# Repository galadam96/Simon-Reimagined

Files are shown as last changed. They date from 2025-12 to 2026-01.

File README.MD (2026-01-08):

# 🎮 Simon Reimagined  

Modern Embedded System Implementation of the Classic Simon Game  

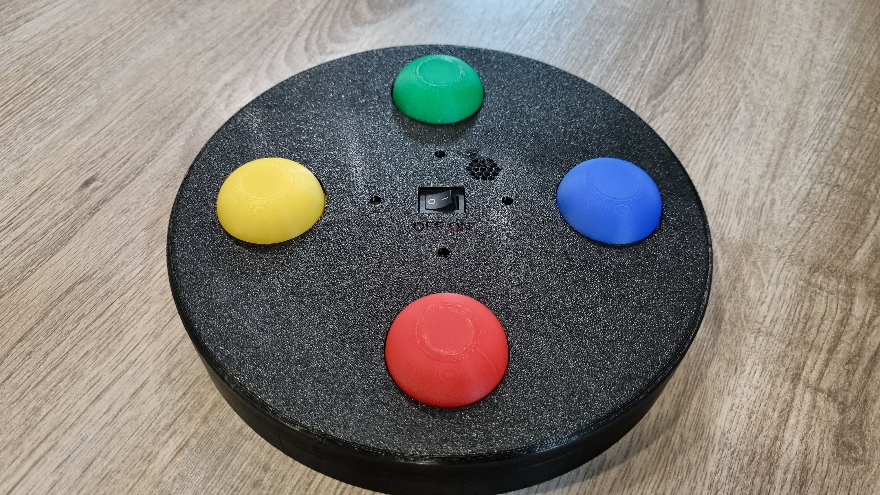
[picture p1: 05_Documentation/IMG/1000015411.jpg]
IMAGE ALT TEXT (http://www.youtube.com/watch?v=DPunw0gCDcM)


## 📌 Overview
Simon Reimagined is a fully redesigned, modern embedded version of the classic Simon memory game.  
The project includes:

- Custom circular PCB (V1.0)
- Arduino Nano–based firmware
- 3D‑printed mechanical housing
- Complete schematics and assembly documentation
- Tinkercad simulation environment
- Professional, print‑ready project documentation

## 🧠 Features
- Four colored buttons with matching LEDs  
- Unique tone for each color  
- Randomly generated sequences  
- Error feedback (audio + visual)  
- Power switch and buzzer  
- Fully custom PCB and enclosure  

## 🛠 Hardware Architecture

## Components
- Arduino Nano (ATmega328P)
- 4× momentary push buttons (Red, Blue, Green, Yellow)
- 4× LEDs with current‑limiting resistors
- Buzzer (4 kHz)
- ON/OFF toggle switch
- Custom circular PCB (designed in EasyEDA)
- 3D‑printed top/bottom housing + latch + buttons

## 💾 Firmware

## Language & Platform
- Arduino IDE (C/C++)
- State‑machine based game logic
- Debounced button input
- Tone generation per color

See the arudino code [here](https://github.com/galadam96/Simon-Reimagined/blob/main/00_Software/SimonGame_V1_4/SimonGame_V1_4.ino)

## 🧪 Simulation
Tinkercad simulation includes:

- Button logic
- LED feedback
- Buzzer tones
- Sequence playback

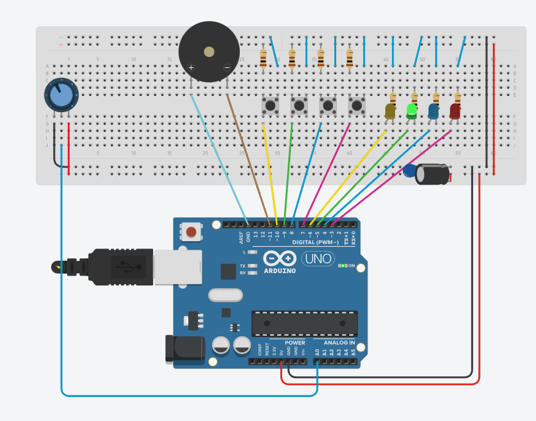
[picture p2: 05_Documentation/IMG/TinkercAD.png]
tinkercad


## 📄 Documentation
A full, print‑ready A4 documentation package is included
Cick [here](https://github.com/galadam96/Simon-Reimagined/blob/main/05_Documentation/Simon_Reimagined_Documentation.pdf) to read it! 

## 📜 License
This project is released under the MIT License.
Feel free to use, modify, and build upon it.

## 👤 Author
Adam Gal  
Embedded Systems Engineer

⭐ If you like this project
Consider giving the repository a star to support my work.

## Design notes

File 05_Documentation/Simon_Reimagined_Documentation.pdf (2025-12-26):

### SIMON REIMAGINED

### Embedded System Project Documentation

### Created by: Adam Gal Version: 1.0

### Date: 2025.12.26

### Project Summary

### A modern reinterpretation of the classic Simon memory game, featuring:

### - Custom PCB

### - Arduino Nano firmware

### - 3D-printed mechanical design

### - Full simulation & testing

### - Complete assembly documentation

### Portfolio Use

### Personal Embedded Engineering Portfolio Project

### © 2025 – Simon Reimagined Project – All rights reserved

### 1. Project Overview

Simon Reimagined is a redesigned memory game based on the classic Simon toy, built around an Arduino Nano microcontroller. The goal is to create a fully functional embedded system that challenges users to memorize and repeat increasingly complex sequences of lights and sounds. The project includes a custom PCB, 3D-printed

housing, and documented firmware.

### 2. Hardware Architecture

### 2.1 Key Components

### - Arduino Nano – microcontroller

### - 4 colored push buttons – user input (red, blue, green, yellow)

### - 4 LEDs – visual feedback

### - Buzzer – audio feedback

### - Toggle switch (ON/OFF) – power control

### - Custom circular PCB – central layout for all components

### 2.2 PCB Design

### Designed by Adam Gal using EasyEDA. Version: V1.0. Included documents:

### - SCH_v1.pdf – schematic diagram

### - Bottom_Plastic.pdf, Top_Plastic.pdf, Latch_Plastic.pdf, Button.pdf – mechanical drawings

### - Assembly.pdf – assembly guide

### 3. Firmware

### 3.1 Features

### - Game start: triggered by a dedicated start button

### - Sequence generation: random color and tone sequence

### - User input: player repeats the sequence

### - Error handling: incorrect input triggers buzzer and LED feedback, then resets

### 4. Mechanical Design

### 4.1 3D Structure

### The housing consists of fourt main parts:

### - Bottom shell – mounting points and power access

### - Top shell – cutouts for buttons and LEDs

### - Latch element – stabilizes button placement

### - Buttons - Custom-designed colored plastic buttons aligned with top shell

cutouts.

### 5. Simulation and Testing

### Simulated in Tinkercad:

### - LED and buzzer behavior

### - Button input and game logic

### - Voltage monitoring and debugging

### 6. Assembly

### Based on Assembly.pdf:

### - Mount Arduino Nano

### - Connect buttons and LEDs

### - Attach buzzer and toggle switch

### - Assemble housing (screws and alignment)

### 7. Attachments

### - Firmware code (Arduino IDE compatible)

### - SCH and PCB designs (EasyEDA)

### - Mechanical drawings (PDF format)

### - 3D renders and photos of the final device

### - Simulation environment (Tinkercad)

//DATE: 2025.10.08
//Author: Gal Adam
// ========================================
// SIMON GAME - Arduino Nano
// ========================================
// A memory game where players repeat an increasingly long sequence of colors. // - 4 colored buttons with LEDs
// - Buzzer for audio feedback
// - Green button (index 2) is used to start the game

// ----- PIN CONFIGURATION -----
const int BUTTON_PINS[4] = {10, 9, 8,7}; // Button inputs (with internal pullup)
const int LED_PINS[4] = {3, 4, 5, 6}; | // LED outputs for each color
const int BUZZER_PIN = 11; | // Buzzer output

// ----- AUDIO TONES -----
const int TONES[4] = {310, 209, 415, 252}; // Unique tone for each color

// ----- GAME VARIABLES -----
const int MAX_SEQUENCE = 100; | // Maximum sequence length
int sequence[MAX_SEQUENCE]; | // Stores the color sequence
int sequenceLength = 0; | // Current sequence length
int userInputIndex = 0; | // Tracks user's position in sequence

// ----- GAME STATES -----
enum GameState {
WELCOME, | // Show startup animation
WAIT_FOR_START, // Wait for player to press start button PLAY_SEQUENCE, // Display the sequence to memorize
USER_INPUT, | // Wait for player to repeat the sequence
GAME_OVER | // Show game over animation
};
GameState gameState = WELCOME;

// ----- DEBOUNCE TIMING -----
unsigned long lastButtonPress = 0; | // Last button press timestamp
const unsigned long debounceDelay = 200; | // Minimum time between button
presses (ms)

// ========================================
// SETUP
// ========================================
void setup() {
// Configure button pins with internal pullup resistors for (int i = 0; i < 4; i++) {
pinMode(BUTTON_PINS[i], INPUT_PULLUP); pinMode(LED_PINS[i], OUTPUT);
}

pinMode(BUZZER_PIN, OUTPUT);

}

// ======================================== // MAIN LOOP
// ======================================== void loop() {
switch (gameState) {
case WELCOME:
welcomeSequence();
gameState = WAIT_FOR_START; break;

case WAIT_FOR_START:
if (waitForStartButton()) {
sequenceLength = 0;
digitalWrite(LED_PINS[2], LOW); // Turn off blinking LED delay(500); // Short pause after start button press gameState = PLAY_SEQUENCE;
}
break;

case PLAY_SEQUENCE:
addToSequence();
playSequence();
userInputIndex = 0;
lastButtonPress = millis(); // Reset debounce timer gameState = USER_INPUT;
break;

case USER_INPUT:
{
int input = readButton();
if (input != -1) {
playColor(input);

// Check if input matches the sequence if (input != sequence[userInputIndex]) { gameState = GAME_OVER;
} else {
userInputIndex++;
// Check if entire sequence was entered correctly if (userInputIndex >= sequenceLength) { delay(500);
gameState = PLAY_SEQUENCE;
}
}
}
}
break;

case GAME_OVER:
gameOver();
gameState = WAIT_FOR_START; break;
}
}

// ======================================== // ADD NEW COLOR TO SEQUENCE
// ========================================
// Adds a random color to the sequence.
// Ensures first color is never green (to avoid confusion with start button). void addToSequence() {
if (sequenceLength < MAX_SEQUENCE) {
int newColor;
do {
newColor = random(0, 4);
} while (sequenceLength == 0 && newColor == 2); // First color cannot be green

sequence[sequenceLength++] = newColor;
}
}

// ======================================== // PLAY ENTIRE SEQUENCE

// ========================================
// Plays back the current sequence for the player to memorize. void playSequence() {
for (int i = 0; i < sequenceLength; i++) { playColor(sequence[i]);
delay(300); // Pause between colors
}
}

// ========================================
// PLAY SINGLE COLOR
// ========================================
// Lights up LED and plays tone for a single color. void playColor(int index) {
int duration = 150;

digitalWrite(LED_PINS[index], HIGH); tone(BUZZER_PIN, TONES[index], duration); delay(duration);
digitalWrite(LED_PINS[index], LOW);
}

// ======================================== // READ BUTTON INPUT
// ========================================
// Non-blocking button read with debounce.
// Returns button index (0-3) or -1 if no button pressed. int readButton() {
// Debounce: ignore inputs that are too close together if (millis() - lastButtonPress < debounceDelay) { return -1;
}

// Check each button
for (int i = 0; i < 4; i++) {
if (digitalRead(BUTTON_PINS[i]) == LOW) { lastButtonPress = millis();

// Wait for button release
while (digitalRead(BUTTON_PINS[i]) == LOW) { delay(10);
}

return i;
}
}
return -1;
}

// ======================================== // GAME OVER ANIMATION
// ======================================== // Flashes all LEDs and plays error sound. void gameOver() {
delay(300); // Wait for button release

// Flash all LEDs 3 times with low buzzer tone for (int i = 0; i < 3; i++) { tone(BUZZER_PIN, 100, 200);
for (int j = 0; j < 4; j++) { digitalWrite(LED_PINS[j], HIGH); }
delay(200);
noTone(BUZZER_PIN);

for (int j = 0; j < 4; j++) { digitalWrite(LED_PINS[j], LOW); }
delay(200);
}

delay(1000); // Pause before allowing restart }

// ========================================
// WELCOME ANIMATION
// ========================================
// Plays startup sequence: cascade effect followed by synchronized flashes. void welcomeSequence() {
int duration = 150;

// Cascade: each color lights up in sequence (2 times)
for (int repeat = 0; repeat < 2; repeat++) {
for (int i = 0; i < 4; i++) { digitalWrite(LED_PINS[i], HIGH); tone(BUZZER_PIN, TONES[i], duration); delay(duration);
digitalWrite(LED_PINS[i], LOW); noTone(BUZZER_PIN);
delay(100);
}
}

// Synchronized flash: all colors at once (4 times) for (int repeat = 0; repeat < 4; repeat++) {
for (int i = 0; i < 4; i++) { digitalWrite(LED_PINS[i], HIGH);
}
tone(BUZZER_PIN, 400, duration); delay(duration);
noTone(BUZZER_PIN);
for (int i = 0; i < 4; i++) { digitalWrite(LED_PINS[i], LOW); }
delay(150);
}
}

// ========================================
// WAIT FOR START BUTTON
// ========================================
// Non-blocking function that blinks green LED while waiting for start button. // Returns true when start button (green, index 2) is pressed.
bool waitForStartButton() {
static unsigned long previousMillis = 0;
const long interval = 300; // Blink interval (ms)
static bool ledState = false;

unsigned long currentMillis = millis();

// Toggle LED at regular intervals
if (currentMillis - previousMillis >= interval) { previousMillis = currentMillis;
ledState = !ledState;
digitalWrite(LED_PINS[2], ledState ? HIGH : LOW); }

// Check if start button is pressed
if (digitalRead(BUTTON_PINS[2]) == LOW) {

while (digitalRead(BUTTON_PINS[2]) == LOW) { delay(10); // Wait for button release
}
return true;
}

return false;
}

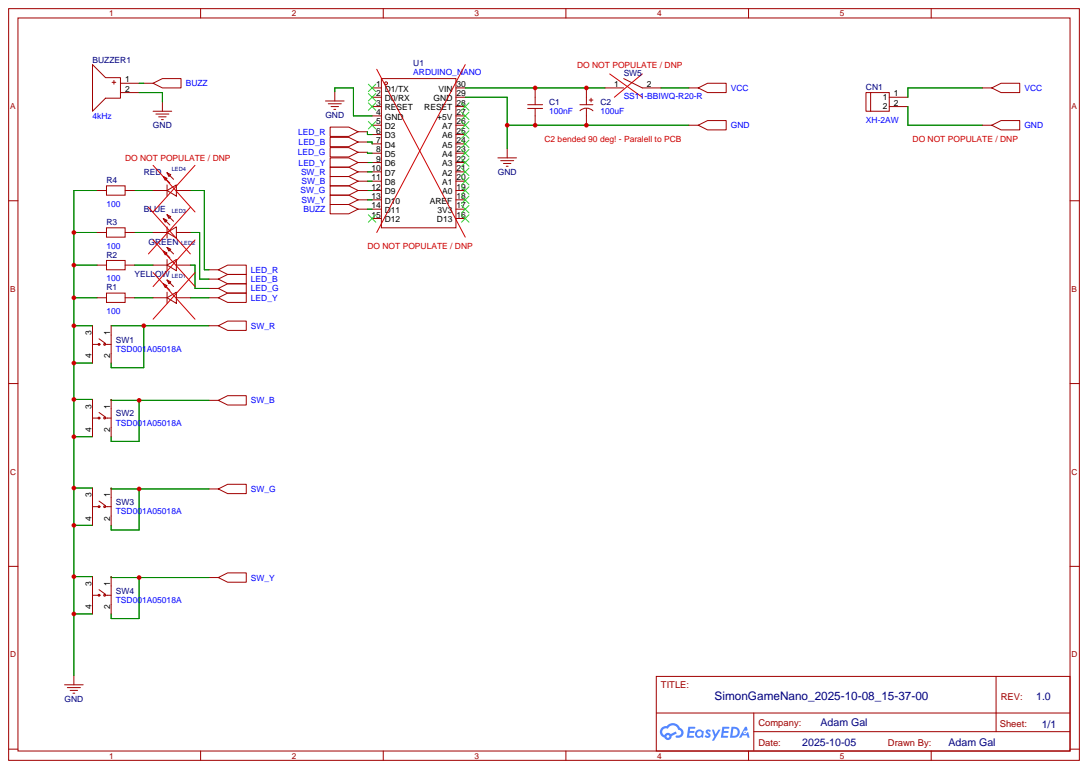
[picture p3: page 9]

DO NOT POPULATE / DNP

C2 bended 90 deg! - Paralell to PCB

LED4 RED

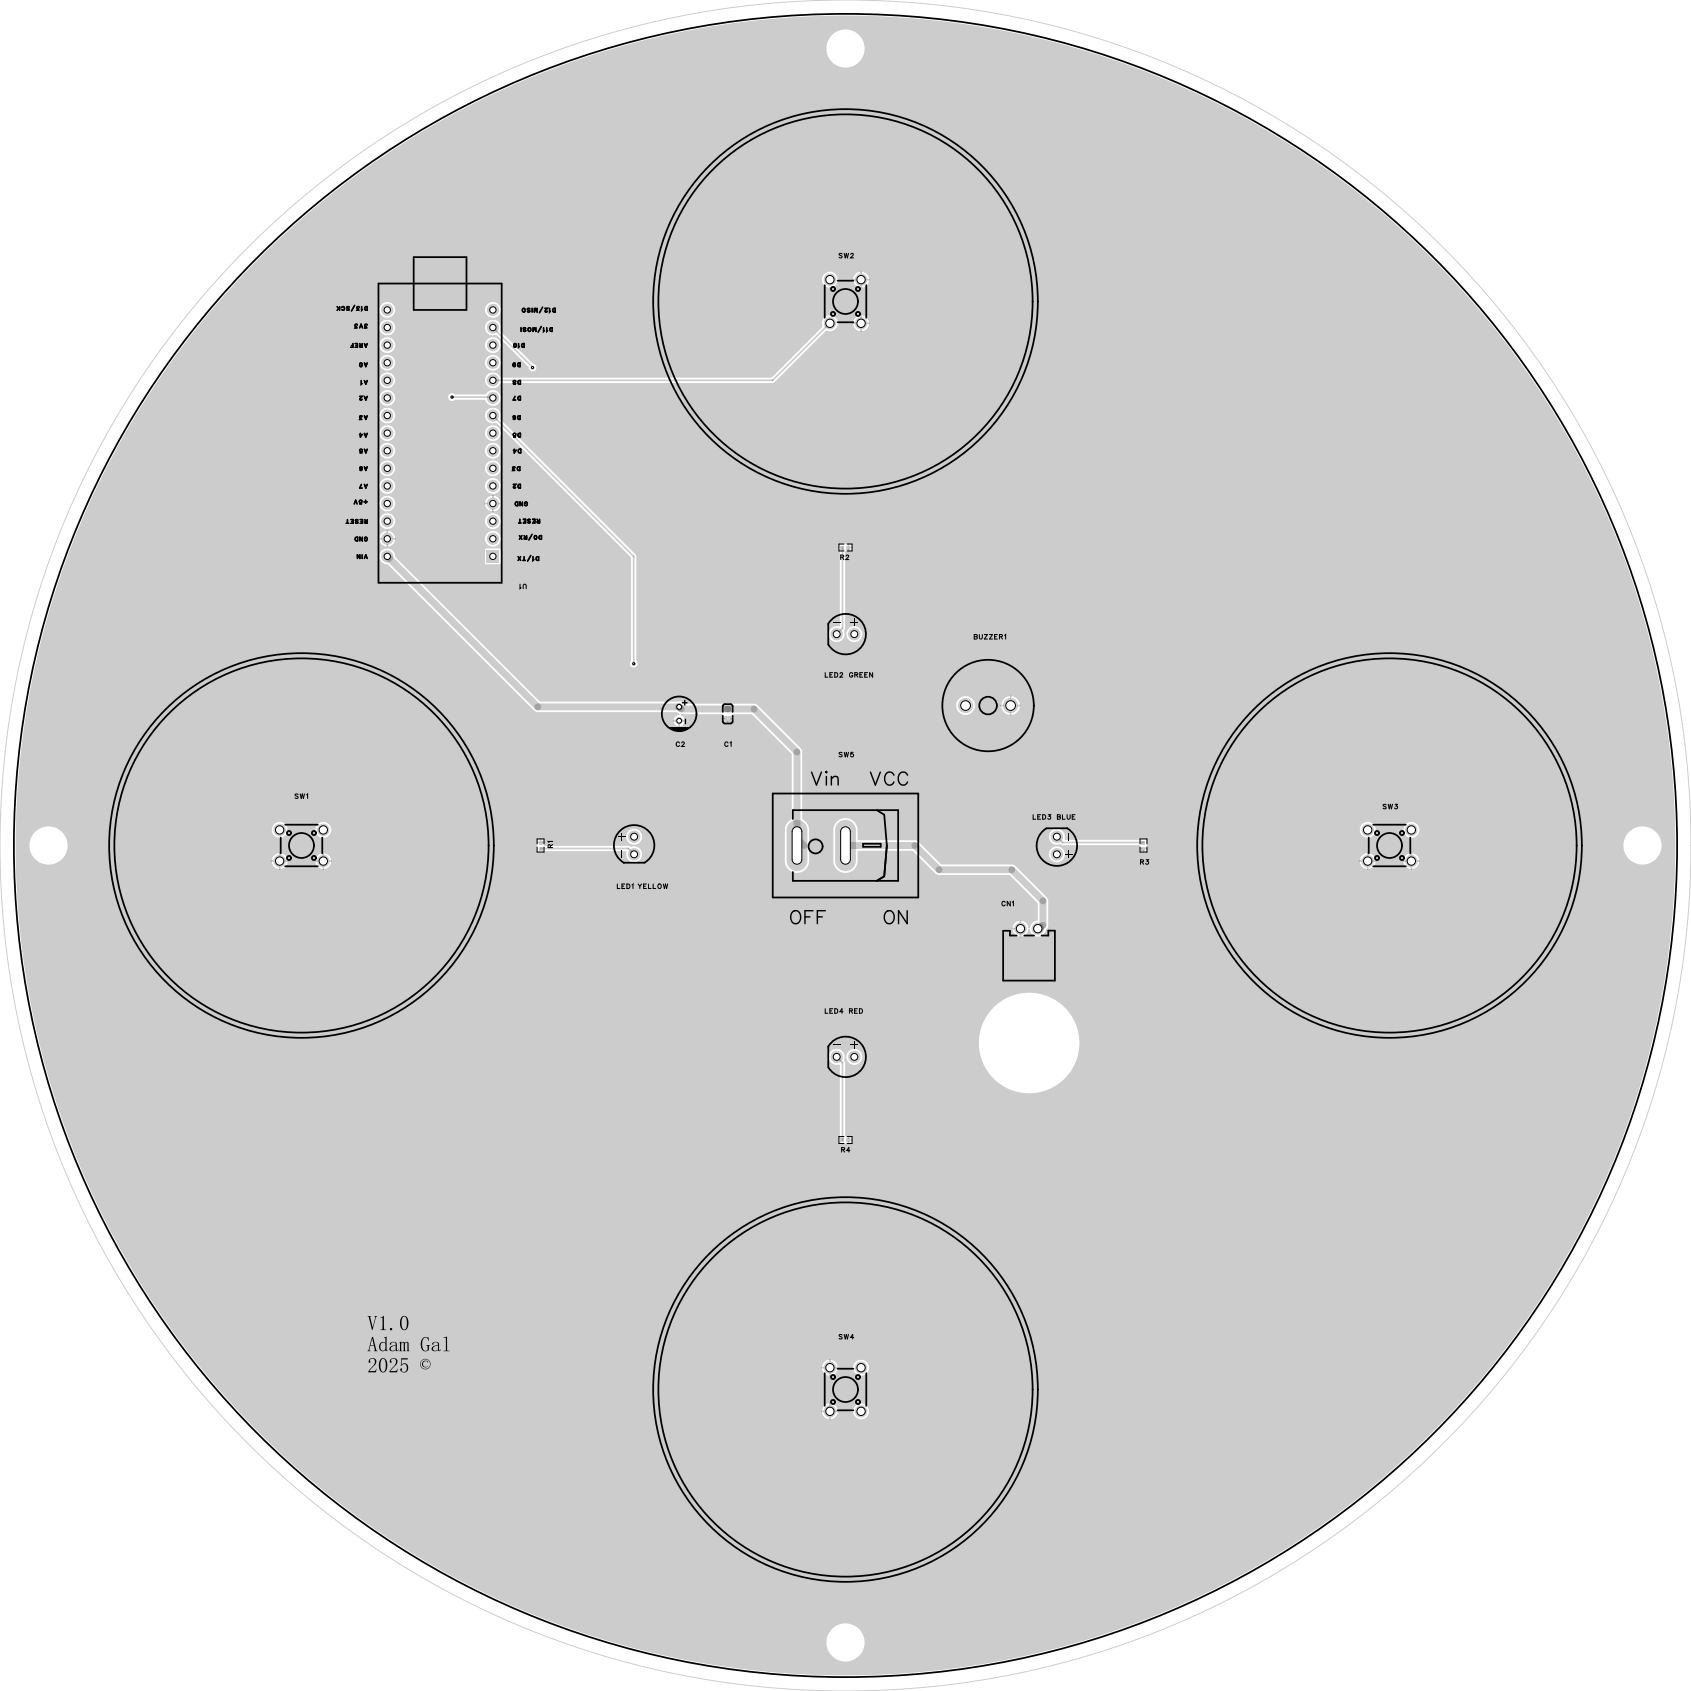
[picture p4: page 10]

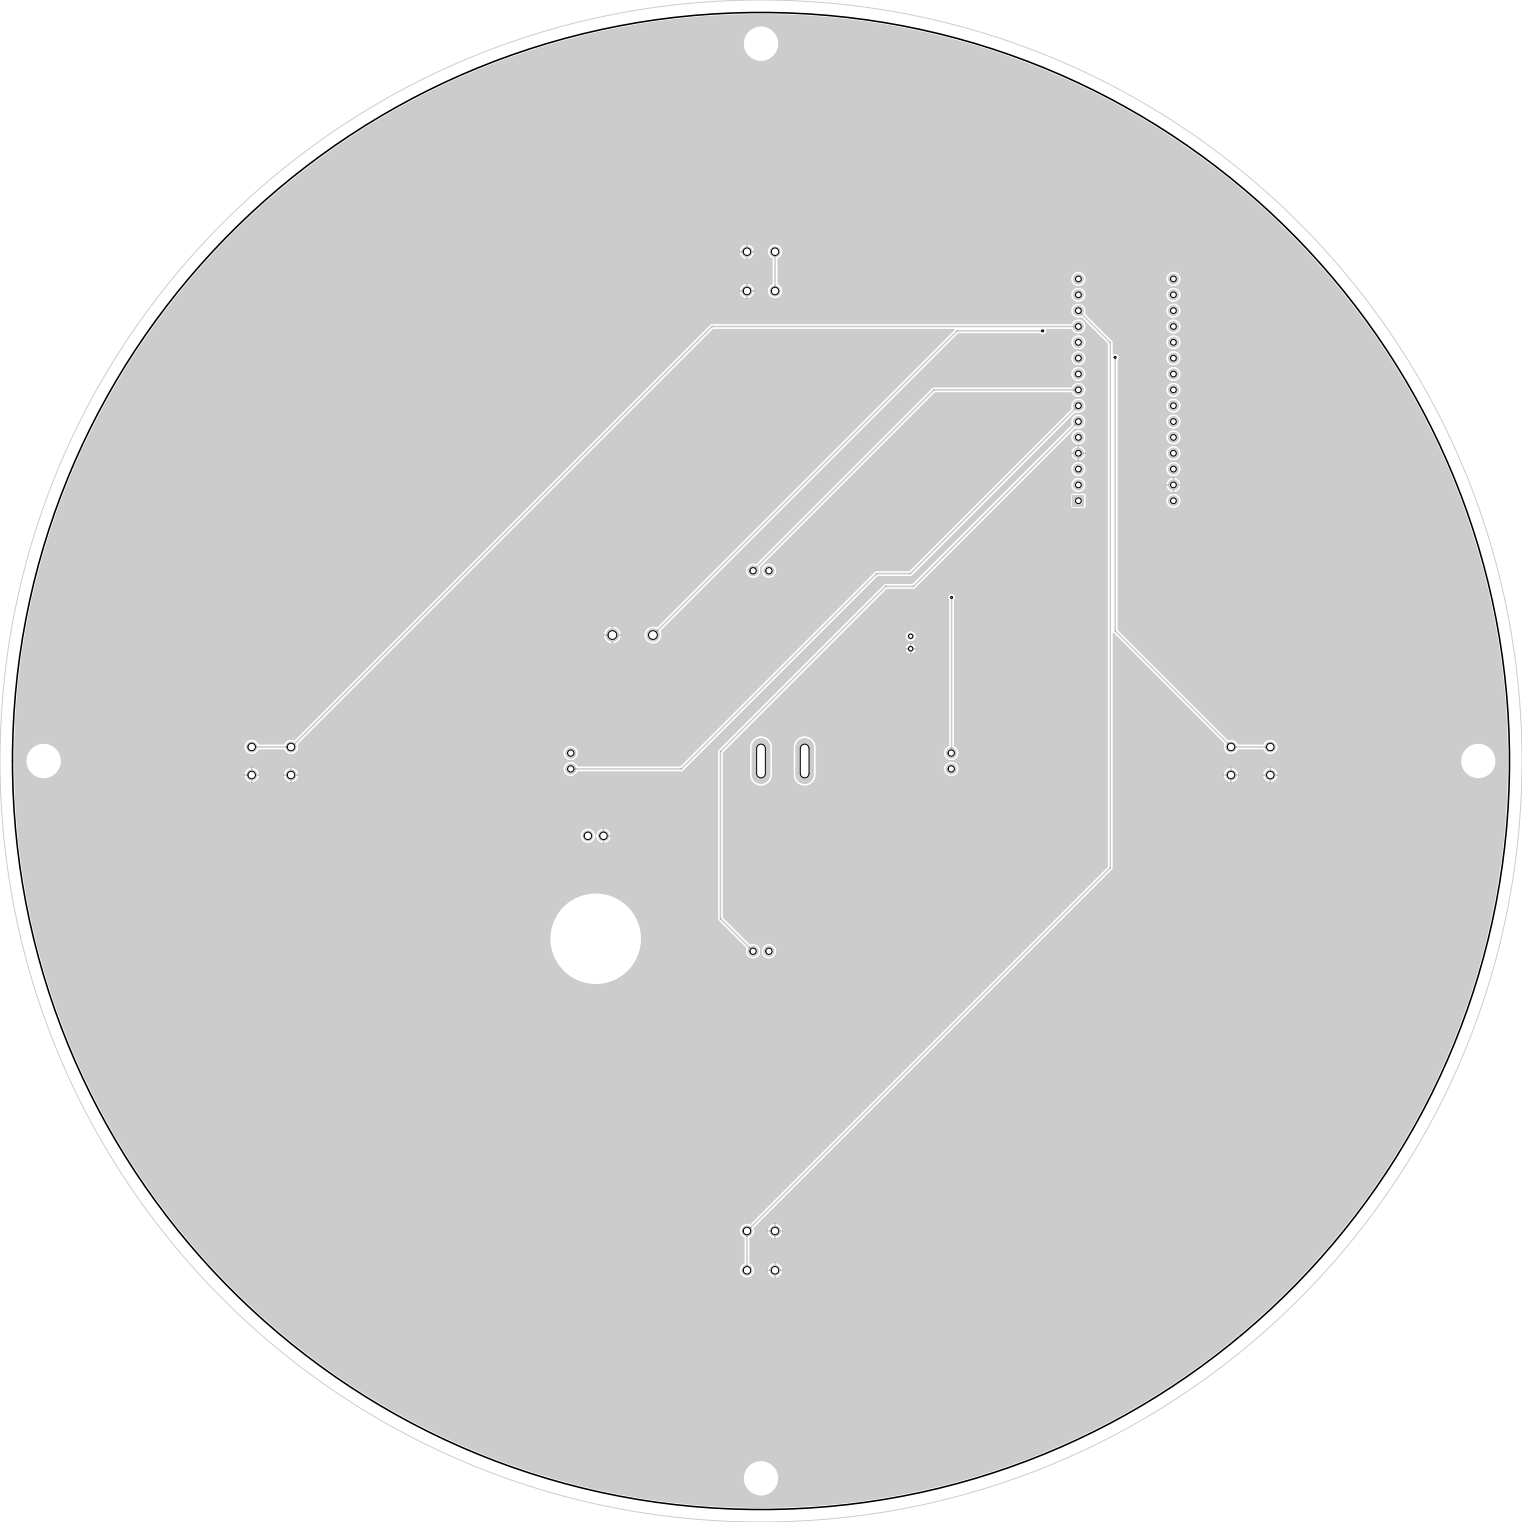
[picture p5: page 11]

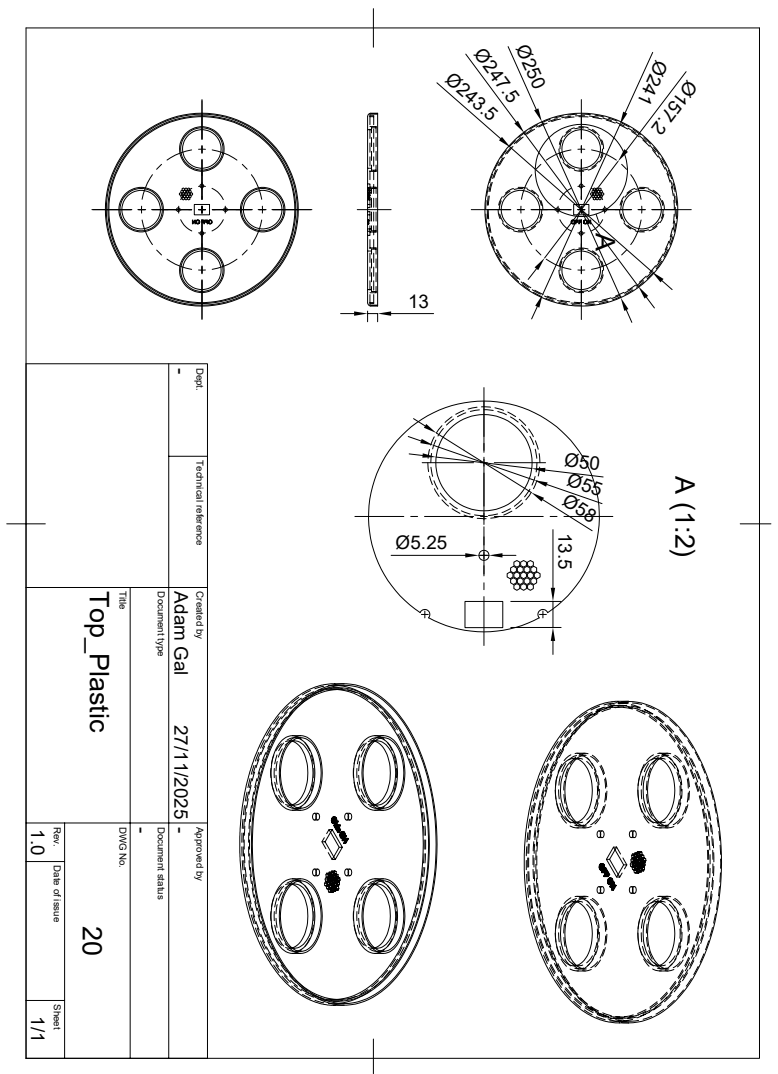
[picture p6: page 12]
- 27/11/2025 1/1 20 Top_Plastic; - Adam Gal -

Dept. Technical reference Created by Approved by Title DWG No. Document type Document status 1.0 Rev. Date of issue Sheet

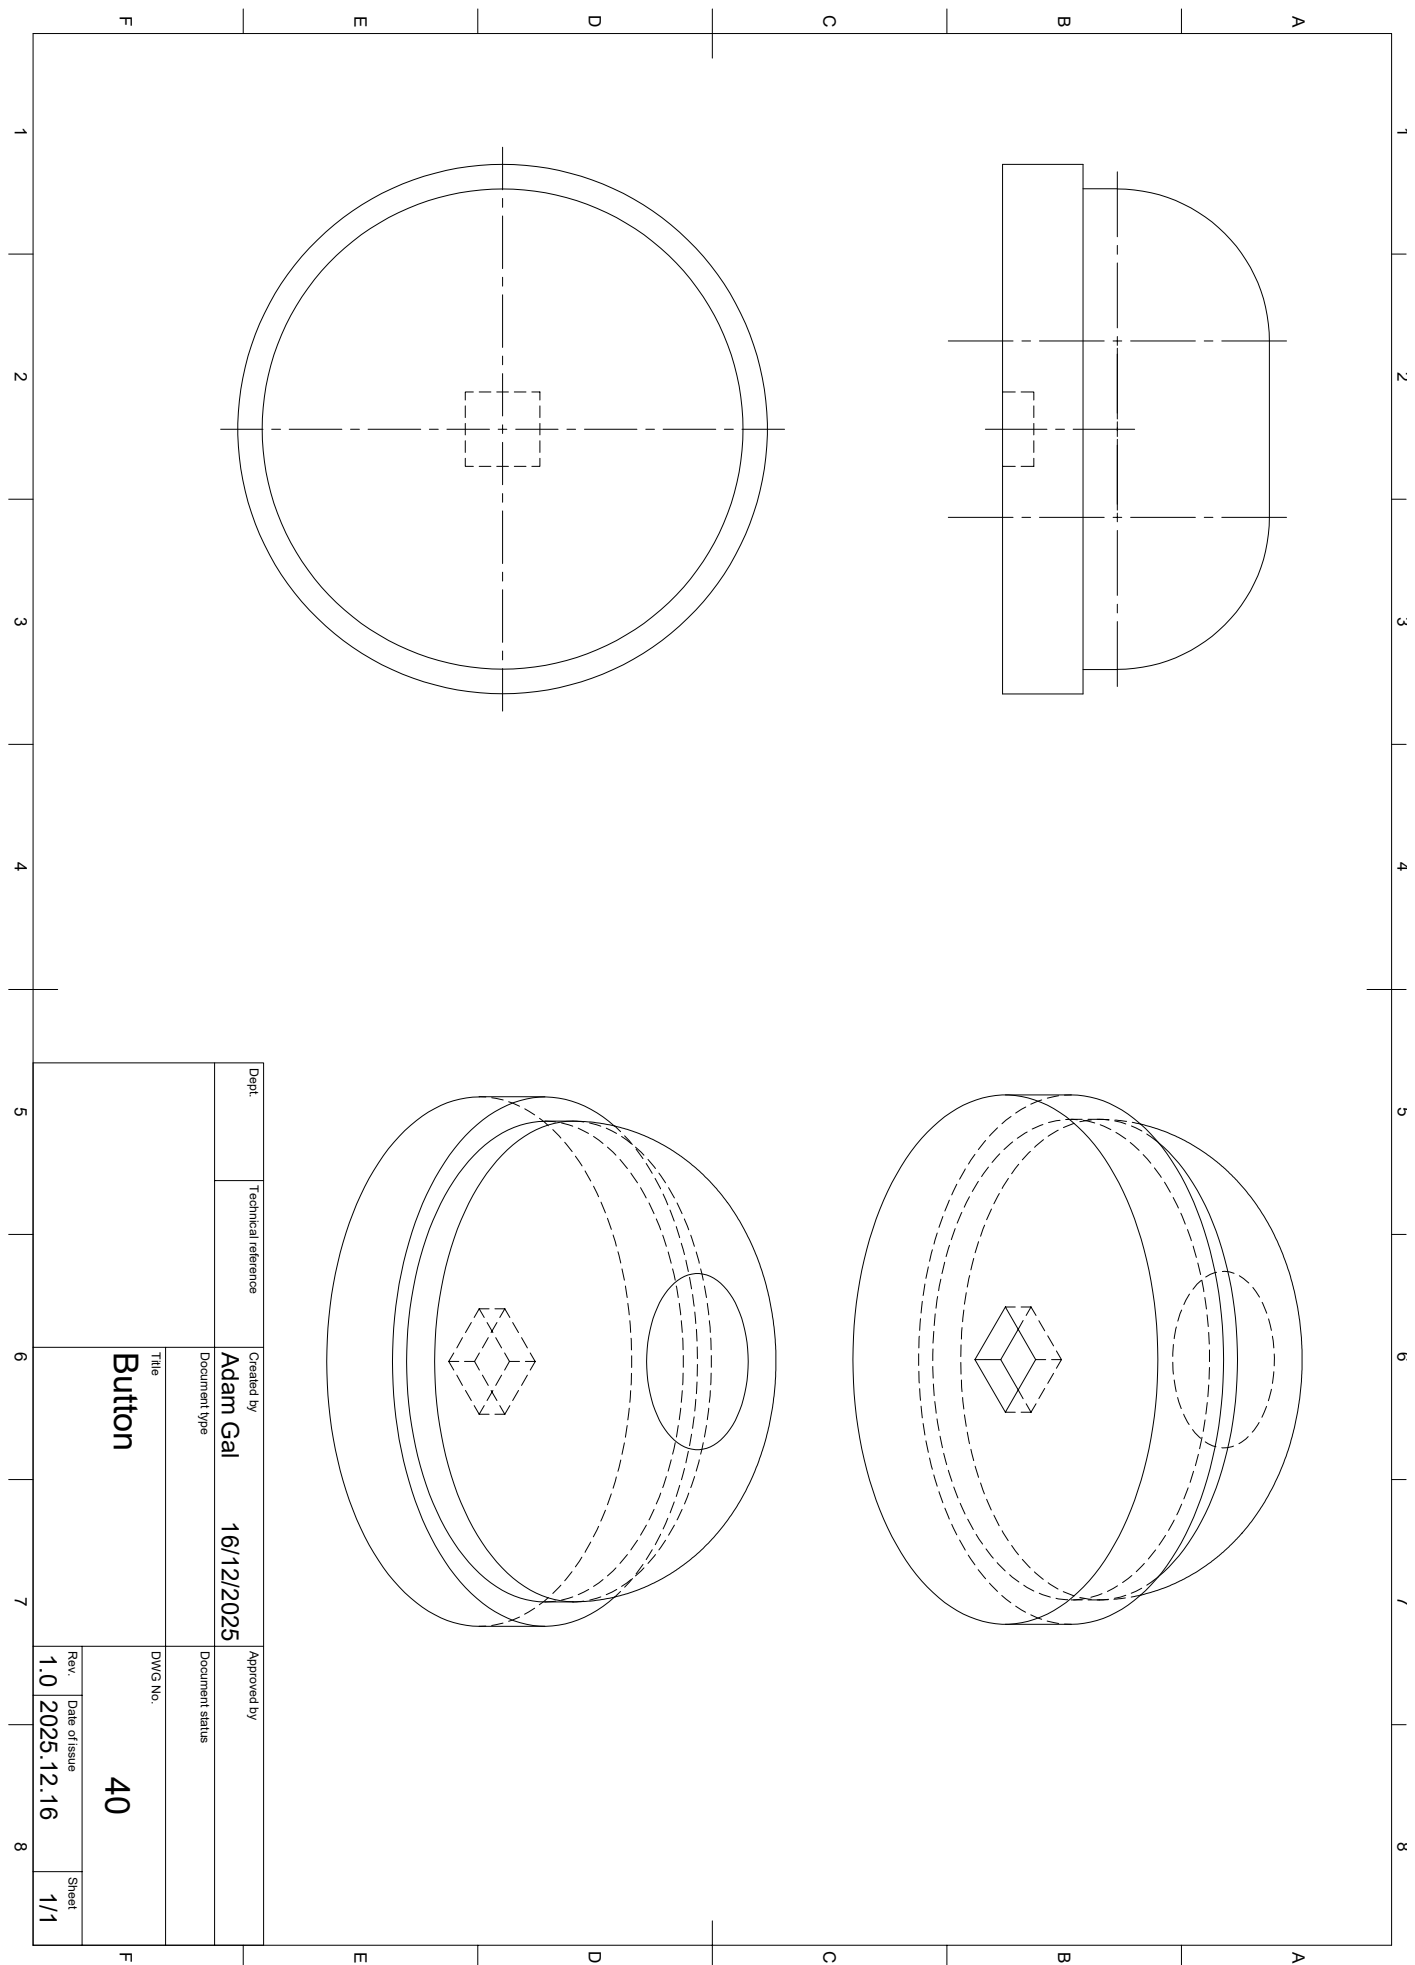
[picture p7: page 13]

1 A 2 3 4 5 6 7 8 1 2 3 4 5 6 7 8 FEDCB FEDCBA Dept. Technical reference Created by Approved by Title DWG No. Document type Document status Rev. Date of issue Sheet 2025.12.16 1.0 16/12/2025 1/1 40 Button Adam Gal

20

# 30 Ø14

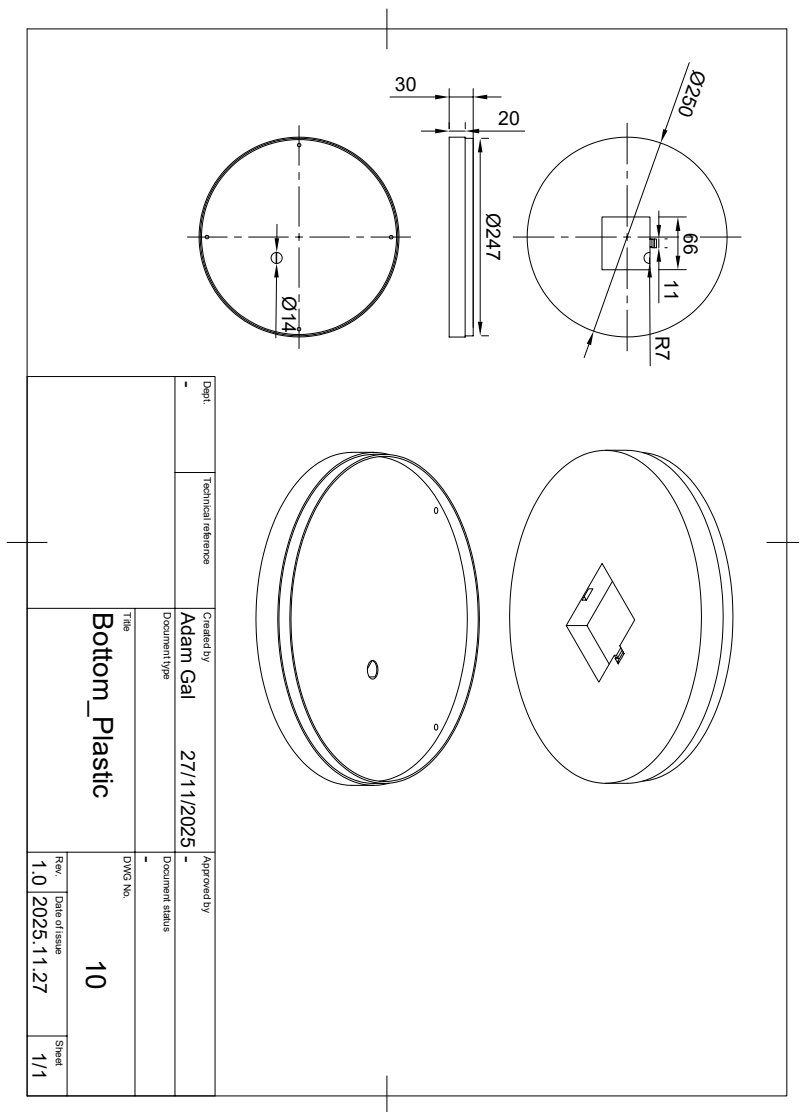
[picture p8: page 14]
- Adam Gal

Dept. Technical reference Created by Approved by Title DWG No. Document type Document status Rev. Date of issue Sheet 2025.11.27 1.0 - 27/11/2025 1/1 10 Bottom_Plastic

65
10

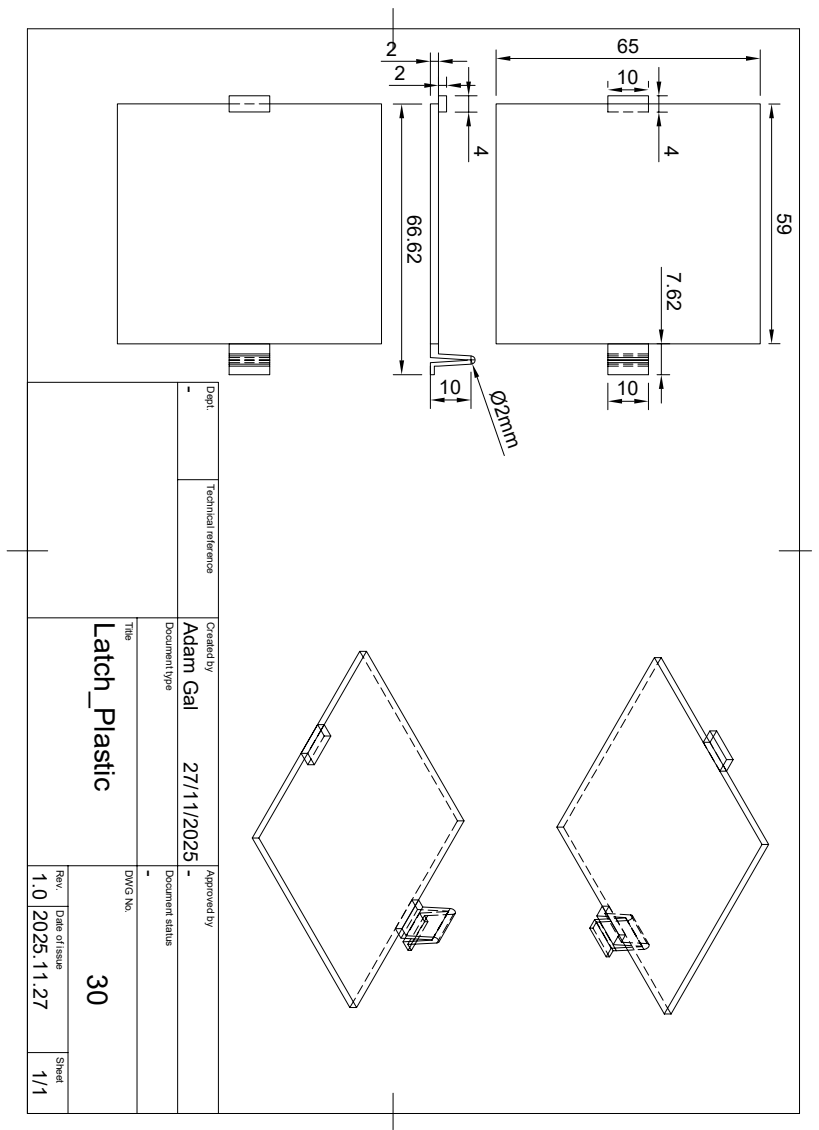
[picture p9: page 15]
- Adam Gal - 59

Dept. Technical reference Created by Approved by Title DWG No. Document type Document status Rev. Date of issue Sheet 2025.11.27 1.0 - 27/11/2025 1/1 30 Latch_Plastic

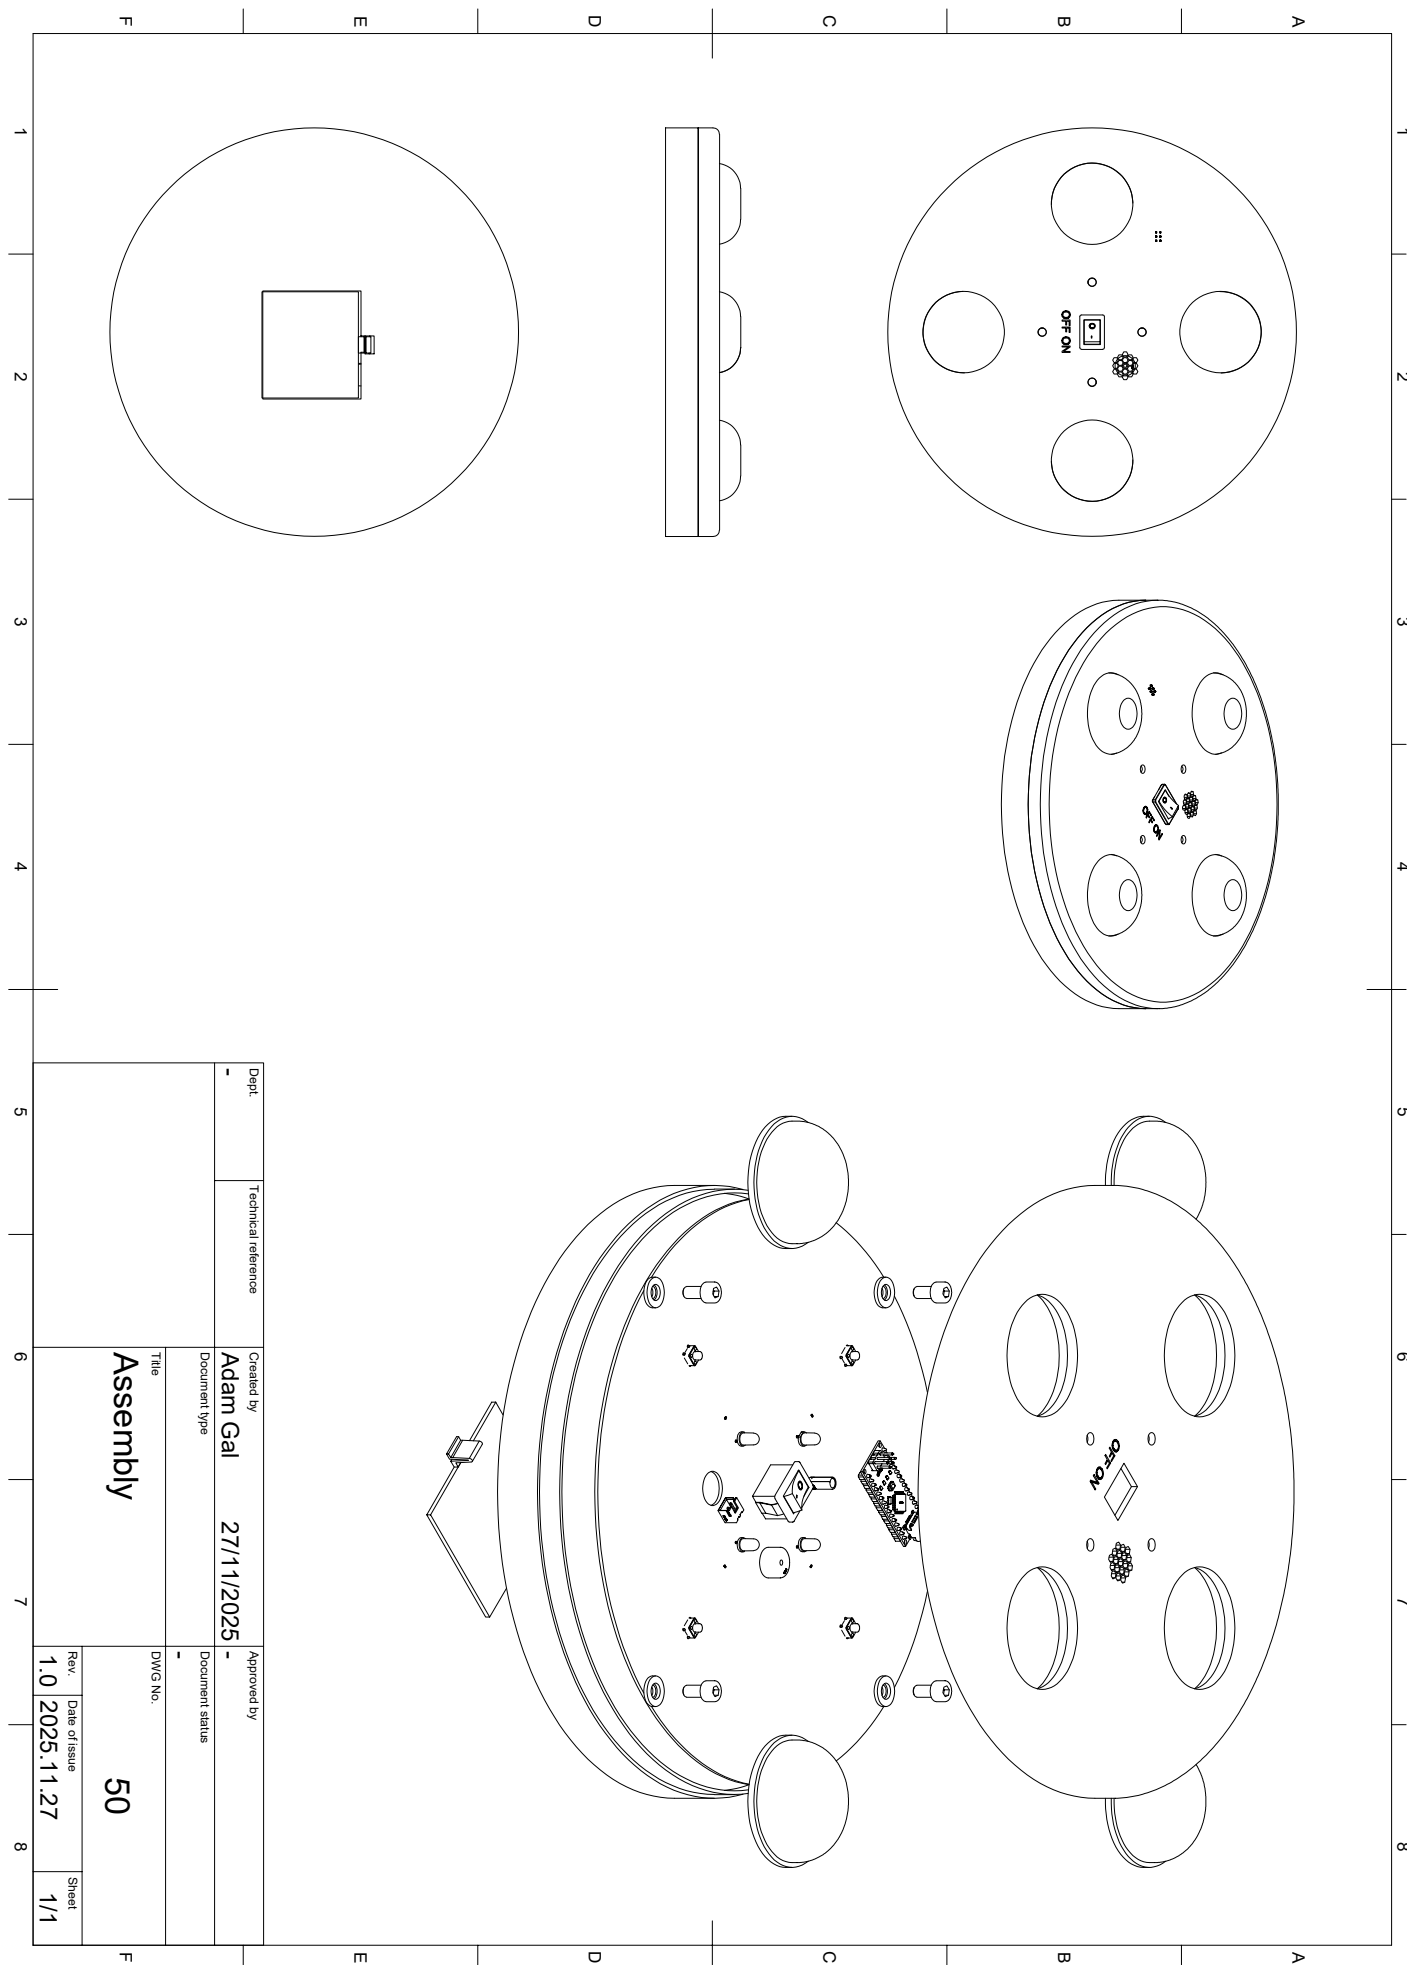
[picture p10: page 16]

1 A 2 3 4 5 6 7 8 1 2 3 4 5 6 7 8 FEDCB FEDCBA Dept. Technical reference Created by Approved by Title DWG No. Document type Document status Rev. Date of issue Sheet 2025.11.27 1.0 - 27/11/2025 1/1 50 Assembly - Adam Gal -

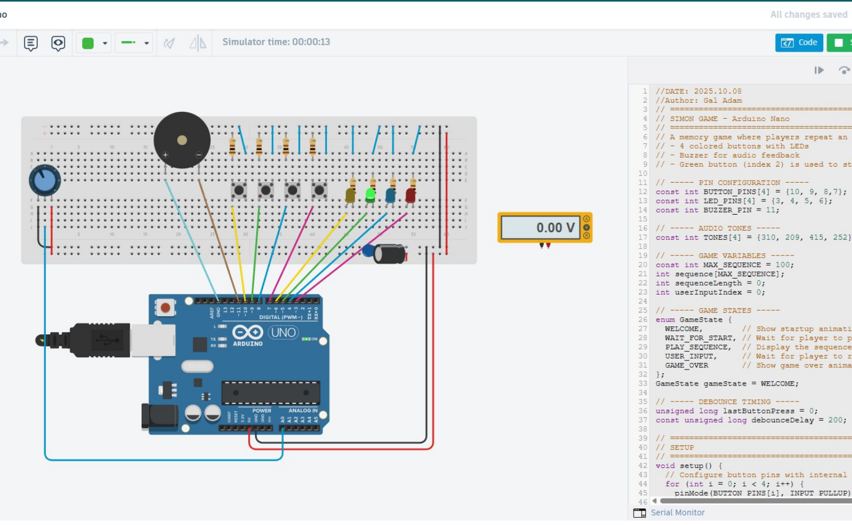
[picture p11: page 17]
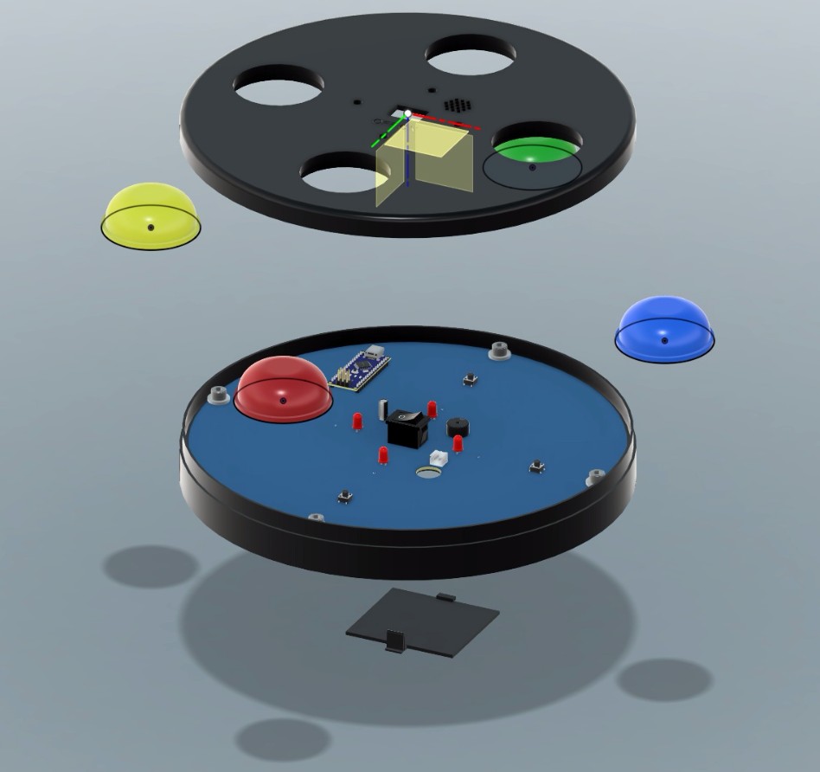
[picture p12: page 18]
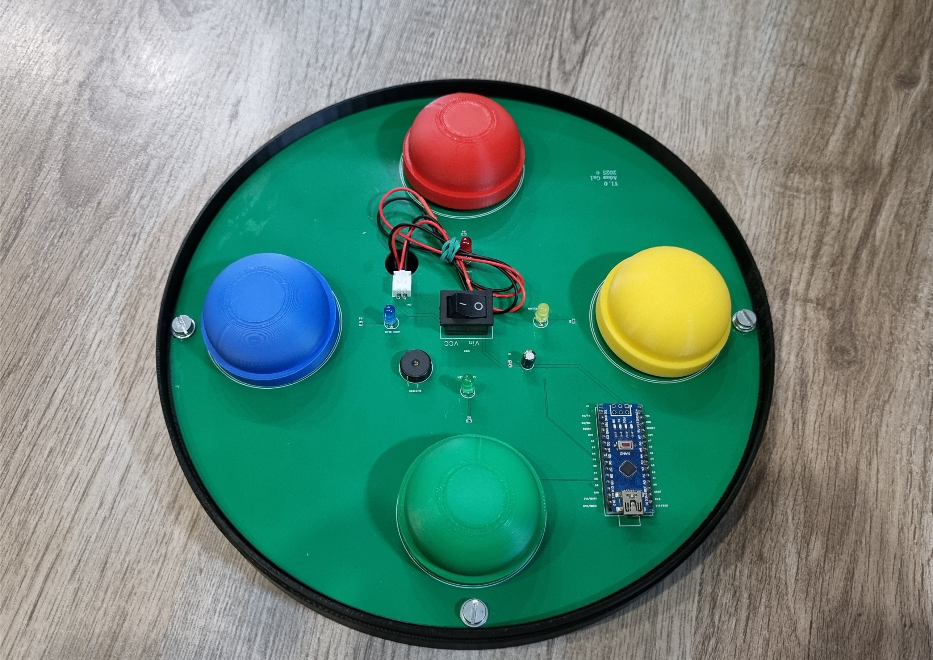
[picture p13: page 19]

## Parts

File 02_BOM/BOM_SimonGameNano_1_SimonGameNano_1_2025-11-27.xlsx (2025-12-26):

No. | Quantity | Comment | Designator | Footprint | Value | Manufacturer Part | Manufacturer | Supplier Part | Supplier | JLCPCB Stock | JLCPCB Price | Unique ID | Symbol | Name | Device
1 | 1 | 4kHz | BUZZER1 | BUZ-TH_BD12.5-P6.50-D1.4 | 4kHz | 1255-P6.5MM | XHXDZ(兴华鑫) | C49246963 | LCSC | 910 | 0.0076 | gge1 | 1255-P6.5MM | 4kHz | 1255-P6.5MM
2 | 1 | 100nF | C1 | C0603 | 100nF | TCC0603X7R104K250CT | CCTC(三环) | C7501158 | LCSC | 30739 | 0.0003 | gge12 | TCC0603X7R104K250CT | 100nF | TCC0603X7R104K250CT
3 | 1 | 100uF | C2 | CAP-TH_BD5.0-P2.00-D0.5-FD-1 | 100uF | 16V100uF CD288 | HRK(鸿瑞凯电子) | C2960195 | LCSC | 41190 | 0.0021 | gge13 | 16V100UF CD288 | 100uF | 16V100uF CD288
4 | 1 | XH-2AW | CN1 | CONN-TH_2P-P2.50_XH-2AW |  | XH-2AW | BOOMELE(博穆精密) | C33132 | LCSC | 82562 | 0.0012 | gge15 | XH-2AW | XH-2AW | XH-2AW_C33132
5 | 4 | 333-2SURD/S530-A3 | LED1,LED2,LED3,LED4 | LED-TH_BD5.9-P2.54-RD_RED |  | 333-2SURD/S530-A3 | EVERLIGHT(亿光) | C87271 | LCSC | 56201 | 0.0045 | BLUE,GREEN,RED,YELLOW | 333-2SURD/S530-A3 | 333-2SURD/S530-A3 | 333-2SURD/S530-A3
6 | 4 | 100Ω | R1,R2,R3,R4 | R0402 | 100Ω | SCR0402J100R | VO(翔胜) | C3017466 | LCSC | 7186 | 0.0001 | gge3,gge4,gge5,gge6 | SCR0402J100R | 100Ω | SCR0402J100R
7 | 4 | TSD001A05018A | SW1,SW2,SW3,SW4 | SW-TH_4P-L6.0-W6.0-P4.50-LS6.3 |  | TSD001A05018A | BZCN(博众电气) | C2888545 | LCSC | 3219 | 0.0016 | gge7,gge8,gge9,gge10 | TSD001A05018A | TSD001A05018A | TSD001A05018A
8 | 1 | SS11-BBIWQ-R20-R | SW5 | SW-TH_SS11-BBIWQ-XX |  | SS11-BBIWQ-R20-R | Legion(六钧) | C309066 | LCSC | 2057 | 0.0424 | gge16 | SS11-BBIWQ-R20-R | SS11-BBIWQ-R20-R | SS11-BBIWQ-R20-R
9 | 1 | ARDUINO_NANO | U1 | ARDUINO_NANO |  | ARDUINO_NANO | null | C9900017879 | LCSC | 0 | 0.0053 | gge5e3b22db8fd4dd14 | ARDUINO_NANO | ARDUINO_NANO | ARDUINO_NANO

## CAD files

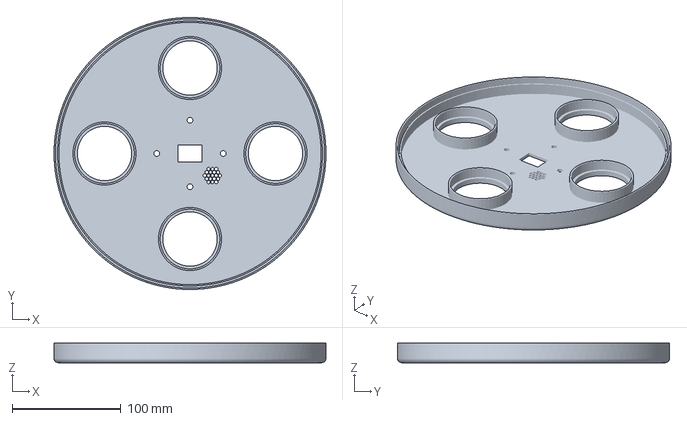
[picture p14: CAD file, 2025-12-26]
04_3D_STP/00_Print_Files/Top_v3_print.3mf
250.0 x 250.0 x 18.0 mm

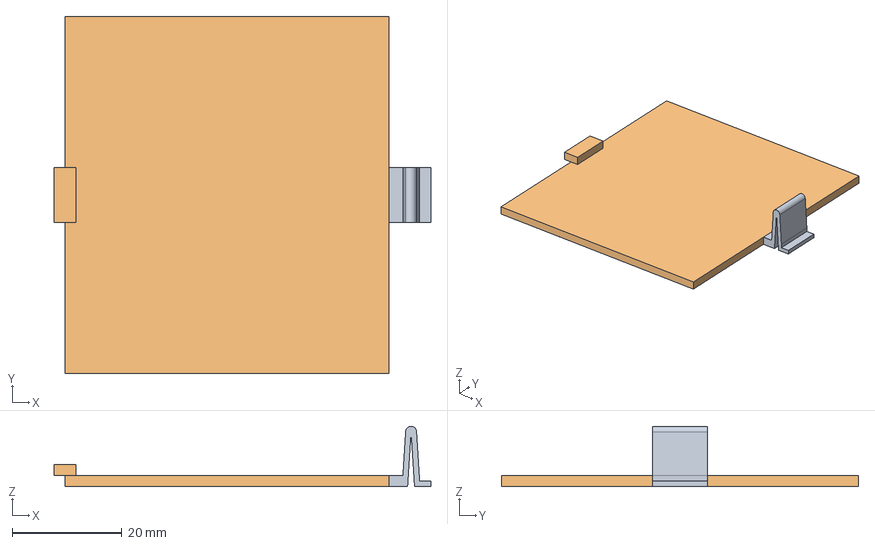
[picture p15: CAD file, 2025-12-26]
04_3D_STP/Latch_v3.step
68.6 x 65.0 x 11.0 mm

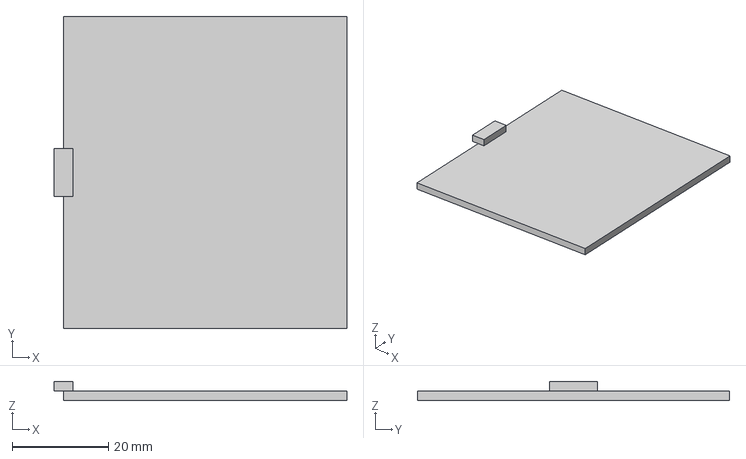
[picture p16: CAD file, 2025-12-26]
04_3D_STP/00_Print_Files/Latch_v3_print.3mf
61.0 x 65.0 x 4.00 mm

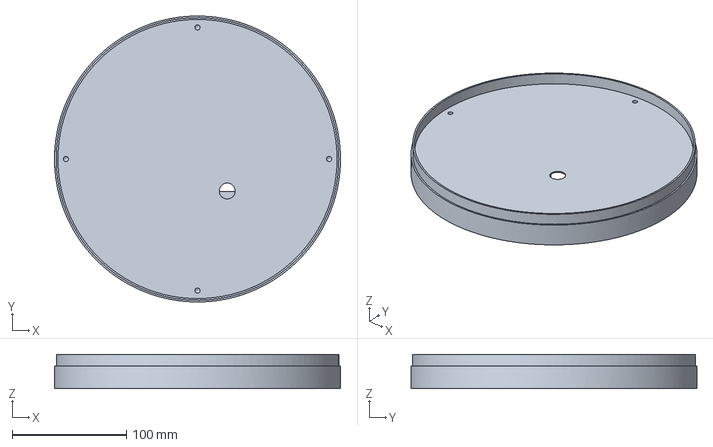
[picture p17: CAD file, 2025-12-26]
04_3D_STP/00_Print_Files/Bottom_v3_print.3mf
250.0 x 250.0 x 30.0 mm

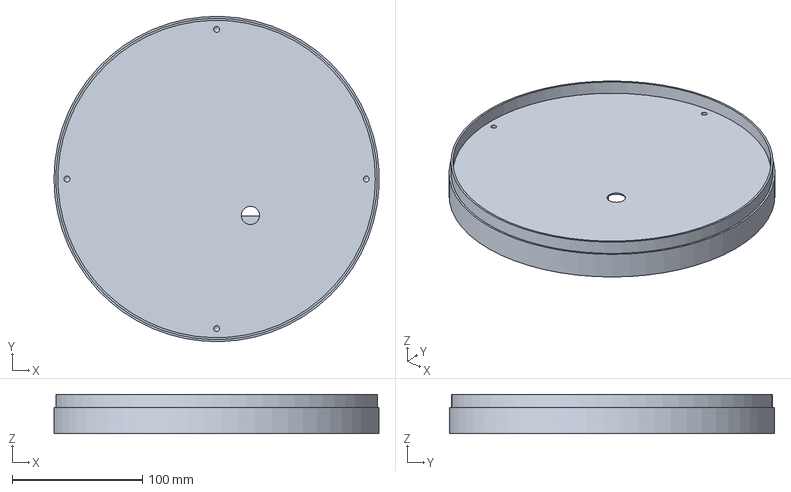
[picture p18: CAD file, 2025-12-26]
04_3D_STP/Bottom_v3.step
249.8 x 249.9 x 30.0 mm

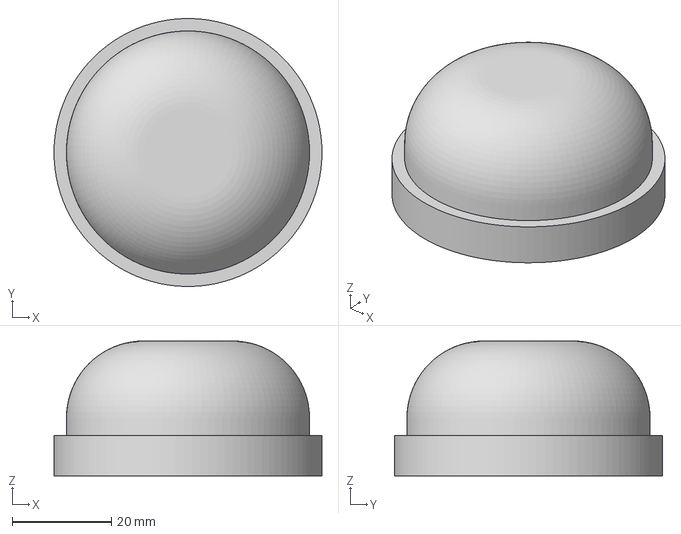
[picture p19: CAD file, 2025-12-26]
04_3D_STP/00_Print_Files/Button_v3_print.3mf
54.0 x 54.0 x 27.2 mm

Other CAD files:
04_3D_STP/Top_v3.step
04_3D_STP/Button_v3.step

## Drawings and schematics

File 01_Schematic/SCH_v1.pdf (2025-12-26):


DO NOT POPULATE / DNP

C2 bended 90 deg! - Paralell to PCB

LED4 RED
